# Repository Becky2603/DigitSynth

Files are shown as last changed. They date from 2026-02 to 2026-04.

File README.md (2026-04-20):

# DigitSynth

DigitSynth is a wearable MIDI controller that interacts with the Roland JD-Xi synthesiser. It allows the user to trigger chords and shape the resulting sound in real time using finger movements.

## Hardware Requirements
 
### Bill of Materials

The table below outlines the hardware components used in this project. Exact component matches are not required, and suitable alternatives will yield comparable results. However, as the software has been developed specifically for the Raspberry Pi, it is strongly recommended to retain this as the target platform.
 
| Component | Part Number | Quantity | Approx. Cost (unit)|
|---|---|---|---|
| Raspberry Pi 5 | Pi 5 4GB | 1 | £105.60 |
| Adafruit ADS1115 | 1085 | 1 | £11.18 |
| Adafruit TLC59711 | 1455 | 1 | £6.73 |
| Spectra Symbol Flex Sensor FLX| FLX-L-055-123-MP | 4 | £8.51 |
| Tactile Switch, 4.3mm | MCDTS2-1N| 4 | £0.17 |
| Kingbright L-7113IT 5mm 2V Red LED 80mcd | 56-0250 | 8 | £0.08 |
| Pisugar S Plus 5000 mAh Raspberry Pi UPS | Pisugar S Plus | 1 | £29.99 |

A MIDI-receiving device is required to complete the setup, either a hardware synthesiser or a software synthesiser running on a connected laptop. In this project, a Roland JD-Xi synthesiser was used, receiving MIDI directly from the Raspberry Pi over USB-B.

### Wiring Diagram:

Wiring diagram

## Architecture

<details>
<summary>UML class diagram</summary>

DigitSynth UML class diagram

</details>

## Software Requirements

### Toolchain
Our build system is CMake, but we provide a simple top-level Makefile to make things easy. Feel free to run the `cmake` commands manually if you are so inclined. The `install-deps.sh` script will automatically install dependencies required by DigitSynth. 

## Installing
A simple install can be performed using the `.deb` package in the latest release. Download `digitsynth-aarch64.deb`, then run ```bash sudo dpkg -i digitsynth-aarch64.deb``` in your terminal after navigating to the directory into which the archive was downloaded. The standalone binary can also be found in the release.  Note that dependencies still need to be installed. 

## Building

### 1.1 Clone the Repository
 
```bash
git clone https://github.com/RTES-Group/DigitSynth.git
cd DigitSynth
```

OR 

### 1.2 Download the release
Find the latest release on the right-hand side of this page. Download either the `.tar.gz` or `.zip`. After downloading and navigating to the download directory: 

#### `zip`
```bash 
unzip DigitSynth-xx.xx.xx.zip

cd DigitSynth-xx.xx.xx
```

#### `tar.gz`
```bash 
tar -xf DigitSynth-xx.xx.xx.tar.gz

cd DigitSynth-xx.xx.xx
```

### 2. Install Dependencies

#### Dependencies

| Library | Purpose | Source |
|---|---|---|
| IIR Filter Library | Digital IIR filter design and processing | [berndporr/iir1](https://github.com/berndporr/iir1) |
| RtMidi | Real-time MIDI input/output | [thestk/rtmidi](https://github.com/thestk/rtmidi) |
| ADS1115 API | Flex sensor measurement | [berndporr/rpi_ads1115](github.com/berndporr/rpi_ads1115) |
| libgpiod | GPIO management | [ligpiod](https://libgpiod.readthedocs.io/en/latest/building.html) | 
| libasound2-dev | ALSA development headers | [libasound2-dev](https://alsa-project.org/) |

Simply run the `install-deps.sh` script:
```bash 
./install-deps.sh
```

### 3. Enable SPI and I2C on the Raspberry Pi:
SPI must be enabled before the project will run:

```bash
sudo raspi-config
# Navigate to: Interface Options → SPI → Enable
# Navigate to: Interface Options → I2C → Enable
```

### 4. Build the project:

```bash
cd application/
make
```

### 5. Run:
```bash
build/digitsynth
```

---

## Unit tests

To run unit tests: 
```bash 
make test
```
---
## User Guide

A full user guide covering button modes, controls, and MIDI mapping is available here:

 [DigitSynth User Guide](docs/HowToUse.pdf)
 
---
## Demonstration Videos

| Demo 1 | LED Mode Demo | Demo 2 |
|---|---|---|
| Demo 1 (https://youtube.com/shorts/CaOxxR7UvKo) | Demo 2 (https://youtube.com/shorts/K6ZXAT-Ynss) | Demo 3 (https://youtube.com/shorts/oUVmrUkGGP4) |

---
## Social Media

Follow our build journey on Instagram: 

We are also awaiting a write-up on [Hackaday.com](https://hackaday.com) about our project, so keep an eye out on their blog!

---

## Contributing

See the issues tab for a list of potential contributions. In particular, we would welcome expanding support for other synths. 

---
## License

This project is licensed under the **MIT License** — see the [`LICENSE`](LICENSE) file for details.
 
You are free to use, modify, and distribute this project. We just ask that you credit the original authors.

---

## Authors & Acknowledgements

Developed by:

- **Logan Brown** — [GitHub](https://github.com/LoganBrownGU)
- **Becky Clarke** — [GitHub](https://github.com/Becky2603)
- **Dougal Harris** — [GitHub](https://github.com/DougalH1)
- **Finn McConville** — [GitHub](https://github.com/finnmcco)
- **Jamie Wedlinscky** — [GitHub](https://github.com/jwedlinscky)
  
As part of the **Real-Time Embedded Systems** module at **University of Glasgow**, *2026*.

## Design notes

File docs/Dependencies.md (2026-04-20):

# Dependencies

This document describes all dependencies required to build and run DigitSynth on Raspberry Pi.

A full installation script is available at `DigitSynth/install-deps.sh`.

---

## System Packages

Installed via `apt`:

| Package | Purpose |
|---|---|
| `autotools-dev` | Build toolchain support for autoconf-based projects |
| `autoconf-archive` | Extended macro library for autoconf |
| `libtool` | Generic shared library support |
| `pkg-config` | Compiler flag helper for installed libraries |
| `alsa` | ALSA sound system |
| `libasound2-dev` | ALSA development headers (required by RtMidi) |

---

## libgpiod

**Version:** 2.2
**Source:** https://mirrors.edge.kernel.org/pub/software/libs/libgpiod/
**Purpose:** Linux GPIO access from userspace — used for hardware pin control on the Raspberry Pi.

### Installation

```bash
curl -S https://mirrors.edge.kernel.org/pub/software/libs/libgpiod/libgpiod-2.2.tar.gz -o libgpiod.tar.gz
tar -xf libgpiod.tar.gz
cd libgpiod-2.2/
./configure --enable-bindings-cxx
make
sudo make install
```

> The `--enable-bindings-cxx` flag is required to build the C++ bindings used by this project.

---

## ADS1115 Raspberry Pi Driver

**Source:** https://github.com/berndporr/rpi_ads1115
**Purpose:** Userspace driver for the ADS1115 16-bit ADC over I2C — used to read analogue input from the flex sensors and potentiometers via SPI.

### Installation

```bash
git clone https://github.com/berndporr/rpi_ads1115.git
cd rpi_ads1115/
cmake .
make
sudo make install
```

> Requires I2C to be enabled on the Raspberry Pi. Enable via `sudo raspi-config` → Interface Options → I2C.

---

## iir1 — IIR Filter Library

**Source:** https://github.com/berndporr/iir1
**Purpose:** Digital IIR filter design and processing — used in `FlexDSP` to apply a 4th order Butterworth low-pass filter to flex sensor data.

### Installation

```bash
git clone https://github.com/berndporr/iir1.git
cd iir1
cmake .
make
sudo make install
```

### Usage in this project

Include the filter header with:

```cpp
#include <iir/Butterworth.h>
```

---

## RtMidi

**Source:** https://github.com/thestk/rtmidi
**Purpose:** Real-time MIDI input/output — used to send MIDI CC messages from the glove controller to a connected synthesiser.

### Installation

```bash
git clone https://github.com/thestk/rtmidi.git
cd rtmidi
cmake . -DRTMIDI_API_ALSA=ON -DRTMIDI_API_JACK=OFF
make
sudo make install
```

> Built with ALSA backend enabled and JACK disabled. ALSA is the default audio/MIDI layer on Raspberry Pi OS.

---

## Notes

- All libraries are installed system-wide via `sudo make install` and are picked up automatically by CMake.
- If CMake cannot find a library after installation, run `sudo ldconfig` to refresh the dynamic linker cache.
- Tested on Raspberry Pi OS 64-bit (Bookworm).

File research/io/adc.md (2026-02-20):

# ADCs
Struggling to find an ADC with a data-ready pin, all seem to be query-based. 

Checked: 
- MCP3008I (microchip)
- ADC128S022 (TI)
- MCP320418 (microchip) 
- ADS78301PWT (TI) 

Possibility of using ADS1256 (TI)
- Programmable timer
- Provides data-ready
- A little pricey (approx. £16)

Could build our own oscillator for timing
- 555 or similar
- Crystal oscillator (maybe too fast)

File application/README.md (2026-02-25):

# Raspberry Pi Application

## How to Build

Generate build files: 

```
cmake -B build
```

Build: 

```
cmake --build build/
```

### Release mode
Run the following to compile with max optimisations and no debug symbols: 

```
cmake -B build -DRELEASE=1
cmake --build build/
```

## How to Run

```
./build/digitsynth
```

## Running unit test

(After building)
```
cmake --build build/ -- test
```

## Dependencies

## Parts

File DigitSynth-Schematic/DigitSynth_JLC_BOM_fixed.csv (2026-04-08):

Designator | Comment | Footprint | LCSC Part # | Mouser Part #
C1 | 100nF | C_0603_1608Metric | C14663
C3 | 100n | C_0603_1608Metric | C14663
C4 | 100n | C_0603_1608Metric | C14663
C5 | 100n | C_0603_1608Metric | C14663
C6 | 100n | C_0603_1608Metric | C14663
C_AVDD_1 | 0.1u | C_0603_1608Metric | C14663
C_AVDD_2 | 10u | C_0805_2012Metric | C15850
C_DVDD_1 | 100n | C_0603_1608Metric | C14663
C_FILT1 | 0.33u | C_0603_1608Metric | C1615
C_FILT2 | 0.33u | C_0603_1608Metric | C1615
C_FILT3 | 0.33u | C_0603_1608Metric | C1615
C_FILT4 | 0.33u | C_0603_1608Metric | C1615
D1 | BZX84C5V6 | SOT-23 | C82471
FB1 | 330Ω | L_0603_1608Metric | C79913
R1 | 1k | R_0603_1608Metric | C21190
R2 | 1k | R_0603_1608Metric | C21190
R3 | 1k | R_0603_1608Metric | C21190
R4 | 1k | R_0603_1608Metric | C21190
R5 | 10k | R_0603_1608Metric | C25804
R6 | 10k | R_0603_1608Metric | C25804
R7 | 10k | R_0603_1608Metric | C25804
R8 | 12k | R_0603_1608Metric | C22790
R9 | 12k | R_0603_1608Metric | C22790
R10 | 12k | R_0603_1608Metric | C22790
R11 | 12k | R_0603_1608Metric | C22790
R12 | 10k | R_0603_1608Metric | C25804
R13 | 10k | R_0603_1608Metric | C25804
R14 | 10k | R_0603_1608Metric | C25804
R15 | 10k | R_0603_1608Metric | C25804
R16 | 5K1 | R_0603_1608Metric | C23186
R17 | 5K1 | R_0603_1608Metric | C23186
U1 | ADS1256IDBR | SSOP-28_5.3x10.2mm_P0.65mm | C28186

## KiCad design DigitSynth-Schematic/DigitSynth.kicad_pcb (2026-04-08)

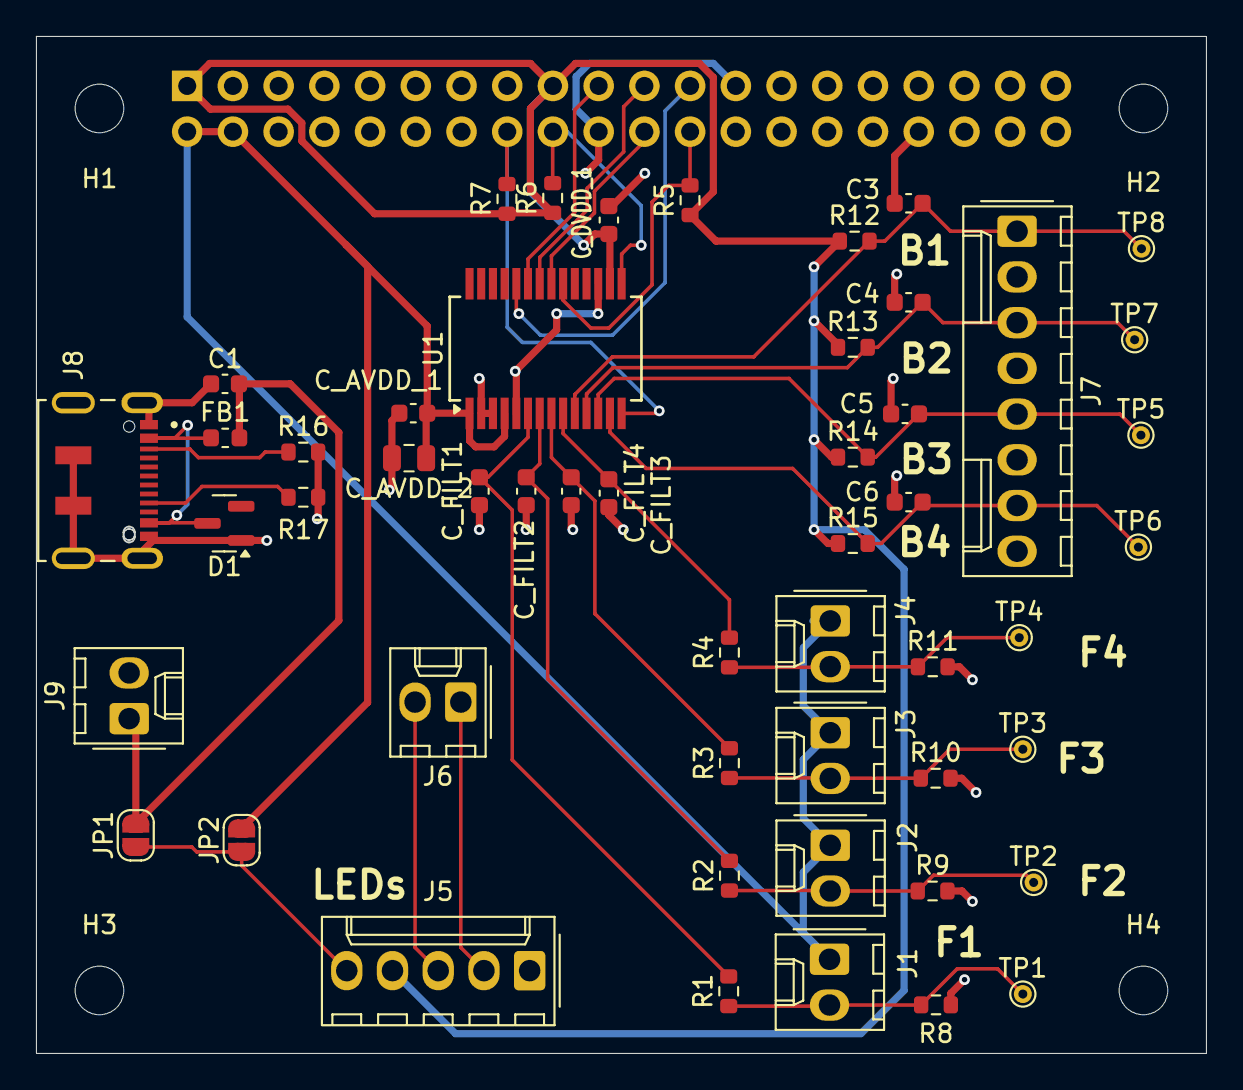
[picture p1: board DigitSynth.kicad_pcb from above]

Board: 2 copper layers, 65.0 x 56.5 mm, 56 parts (1 on the bottom side), 29 nets.

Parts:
C1: 100nF; C_0603_1608Metric
C3, C4, C5, C6: 100n; C_0603_1608Metric
C_AVDD_1: 0.1u; C_0603_1608Metric
C_AVDD_2: 10u; C_0805_2012Metric
C_DVDD_1: 100n; C_0603_1608Metric
C_FILT1, C_FILT2, C_FILT3, C_FILT4: 0.33u; C_0603_1608Metric
D1: BZX84C5V6; SOT-23
FB1: 330Ω; L_0603_1608Metric
H1, H2, H3, H4: MountingHole; MountingHole_2.7mm_M2.5
J1, J2, J3, J4, J6, J9: Conn_01x02_Pin; Molex_KK-254_AE-6410-02A_1x02_P2.54mm_Vertical
J5: Conn_01x05_Pin; Molex_KK-254_AE-6410-05A_1x05_P2.54mm_Vertical
J7: Conn_01x08; Molex_KK-254_AE-6410-08A_1x08_P2.54mm_Vertical
J8: USB_C_Receptacle_USB2.0_JAE; JAE_DX07S016JA1R1500
JP1, JP2: Jumper_2_Open; SolderJumper-2_P1.3mm_Open_RoundedPad1.0x1.5mm
J_RPI1: THD-20-R; PinHeader_2x20_P2.54mm_Vertical
R1, R2, R3, R4: 1k; R_0603_1608Metric
R5, R6, R7, R12, R13, R14, R15: 10k; R_0603_1608Metric
R8, R9, R10, R11: 12k; R_0603_1608Metric
R16, R17: 5K1; R_0603_1608Metric
TP1, TP2, TP3, TP4, TP5, TP6, TP7, TP8: TestPoint; TestPoint_THTPad_D1.0mm_Drill0.5mm
U1: ADS1256IDBR; SSOP-28_5.3x10.2mm_P0.65mm

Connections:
+3V3_PI: C_DVDD_1.1, J5.4, J_RPI1.1, J_RPI1.17, R5.1, R6.1, R7.1, R12.1, R13.1, R14.1, R15.1, U1.16 (DVDD)
+5V_EXT: C1.1, FB1.2, J9.1, JP1.2 (B)
+5V_PI: C_AVDD_1.1, C_AVDD_2.1, J1.1, J2.1, J3.1, J4.1, JP2.2 (B), J_RPI1.2, J_RPI1.4, U1.1 (AVDD), U1.4 (VREFP)
/ADC Flex/ADC_CS: J_RPI1.24, R5.2, U1.20 (~CS)
/ADC Flex/ADC_DRDY: J_RPI1.22, U1.21 (~DRDY)
/ADC Flex/ADC_RESET: J_RPI1.18, R6.2, U1.15 (~RESET)
/ADC Flex/ADC_SYNC_PDWN: J_RPI1.16, R7.2, U1.14 (~SYNC,_~PDWN)
/ADC Flex/BTN_1: C3.1, J7.1, R12.2, TP8.1, U1.10 (AIN4)
/ADC Flex/BTN_2: C4.1, J7.3, R13.2, TP7.1, U1.11 (AIN5)
/ADC Flex/BTN_3: C5.1, J7.5, R14.2, TP5.1, U1.12 (AIN6)
/ADC Flex/BTN_4: C6.1, J7.7, R15.2, TP6.1, U1.13 (AIN7)
/ADC Flex/FLEX1_V: J1.2, R1.1, R8.1, TP1.1
/ADC Flex/FLEX2_V: J2.2, R2.1, R9.1, TP2.1
/ADC Flex/FLEX3_V: J3.2, R3.1, R10.1, TP3.1
/ADC Flex/FLEX4_V: J4.2, R4.1, R11.1, TP4.1
/ADC Flex/SPI0_MISO: J_RPI1.21, U1.22 (DOUT)
/ADC Flex/SPI0_MOSI: J_RPI1.19, U1.23 (DIN)
/ADC Flex/SPI0_SCLK: J_RPI1.23, U1.24 (SCLK)
GND: C1.2, C3.2, C4.2, C5.2, C6.2, C_AVDD_1.2, C_AVDD_2.2, C_DVDD_1.2, C_FILT1.2, C_FILT2.2, C_FILT3.2, C_FILT4.2, D1.1 (A), J5.1, J7.2, J7.4, J7.6, J7.8, J8.A1 (GND), J8.A12 (GND), J8.S1 (SHIELD), J9.2, J_RPI1.6, J_RPI1.9, J_RPI1.14, J_RPI1.20, J_RPI1.25, J_RPI1.30, J_RPI1.34, J_RPI1.39, R8.2, R9.2, R10.2, R11.2, R16.2, R17.2, U1.2 (AGND), U1.3 (VREFN), U1.5 (AINCOM), U1.17 (DGND)
unnamed: D1.3 (K), FB1.1, J8.A4 (VBUS), J8.B4 (VBUS)
unnamed: J5.5, JP1.1 (A), JP2.1 (A)
unnamed: J8.A5 (CC1), R16.1
unnamed: J8.B5 (CC2), R17.1
unnamed: C_FILT1.1, R1.2, U1.6 (AIN0)
unnamed: C_FILT2.1, R2.2, U1.7 (AIN1)
unnamed: C_FILT3.1, R3.2, U1.8 (AIN2)
unnamed: C_FILT4.1, R4.2, U1.9 (AIN3)
SPI2_CLK: J5.2, J6.1
SPI2_DATA: J5.3, J6.2

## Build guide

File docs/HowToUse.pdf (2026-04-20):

# How to Use DigitSynth

Physical Setup
- Left index finger
- LED: TLC59711 pins G0
- Button: Pi GPIO 14
- Left middle finger
- LED: TLC59711 pins G1
- Button: Pi GPIO 15
- Left ring finger
- LED: TLC59711 pins R0
- Button: Pi GPIO 18
- Left pinkie
- LED: TLC59711 pins B1
- Button: Pi GPIO 23
- Right index finger
- LED: TLC59711 pins B0
- Flex sensor: ADC pin A3
- Right middle finger
- LED: TLC59711 pins R2
- Flex sensor: ADC pin A0
- Right ring finger
- LED: TLC59711 pins R1
- Flex sensor: ADC pin A2
- Right pinkie
- LED: TLC59711 pins G2
- Flex sensor: ADC pin A1

How it works
DigitSynth is a wearable MIDI controller that interacts with the Roland JD-Xi synthesiser. It allows the user to trigger chords and shape the resulting sound in real time using finger movements.

Chords are sustained infinitely once triggered, and only stop when switching to a new chord.

The right hand is used to shape the sound. Each flex sensor controls a different synth parameter. The index finger adjusts the cutoff frequency of a low-pass filter, allowing the sound to move from bright and sharp to dull and muted as the finger bends.

The middle and ring fingers control a low-frequency oscillator (LFO) which modulates the filter. The middle finger sets the LFO rate, which determines how quickly the modulation occurs, while the ring finger controls the depth of the LFO i.e. how strong the effect is.

The character of the modulation depends on the shape of the LFO. A sine wave produces smooth changes, a square wave creates sudden switching between values, and the sample-and-hold (SH) mode introduces a random stepped modulation.

The pinkie controls pitch detuning. When held straight, the pitch remains stable. As the finger bends, the pitch becomes increasingly detuned.

Modes of Operation
DigitSynth operates in two modes: a chord mode for live changes between chords, and a normal mode for extended system control.

In chord mode, the four buttons on the left hand each correspond to a specific chord. Pressing a button will immediately switch to that chord. The index finger triggers an Fmaj9 chord, the middle finger plays an Amin11 chord, the ring finger plays a Gsus2 chord, and the pinkie plays a Cmaj7 chord. Pressing the button corresponding to the currently active chord exits chord mode and returns the system to normal mode.

In normal mode, the same buttons are used to control system behaviour. The index finger is used to enter chord mode. The middle finger toggles the LFO on or off. The ring finger cycles through the available LFO shapes (sine, square, and SH). The pinkie switches between the two LED display modes.

LED Behaviour
The LEDs either provide visual feedback or an aesthetic animation, depending on user selection.

In responsive mode, the LEDs communicate the internal state of the system. The left index LED indicates whether the system is in normal mode (on) or chord mode (off). The left middle finger LED shows whether the LFO is enabled (on). The left ring finger LED indicates the current LFO shape using brightness levels: off for sine, medium for square, and full brightness for SH. The left pinkie LED is always on in responsive mode. The brightness of the LEDs on the right hand reflect the position of the flex sensors, giving a visual indication of parameter values.

Alternatively, the LEDs can be set to a ripple mode, where a continuous animated pattern plays across all LEDs. In this mode, no parameter feedback is shown.

Startup Behaviour
On boot, DigitSynth starts in normal mode with an Amin11 chord playing (the chord mapped to the left middle finger). The LEDs are in responsive mode, and the LFO is enabled with a sine wave shape.

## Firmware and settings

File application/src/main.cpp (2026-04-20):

#include "synth-controller.hpp"
#include "tlc59711.hpp"
#include "adc-driver.hpp"
#include "button-driver.hpp"
#include "flex-sensor.hpp"
#include "gpio.hpp"
#include "midi-driver.hpp"
#include "patterns.hpp"
#include "voltage-scaler.hpp"
#include <condition_variable>
#include <iostream>
#include <memory>
#include <mutex>

int main() {
    gpio::setupGpio();
    std::condition_variable c;
    std::mutex m;
    bool done = false;
    
    auto bd = std::make_unique<button_driver::ButtonDriver>();
    bd->registerAllButtonsCallback([&c, &m, &done] () {
        std::unique_lock lock(m);
        done = true;
        lock.unlock();
        c.notify_all();
    });
    
    auto tlc = led_driver::TLC59711("/dev/spidev0.0", 1'000'000);
    auto pattern = led_pattern::PatternRipple(tlc);
    tlc.start();
    SynthController synth(
        tlc,
        pattern,
        std::move(bd),
        std::make_unique<flex_sensor::FlexSensor>(
            std::make_unique<adc_driver::Ads1115Driver>(),
            std::make_unique<voltage_scaler::VoltageScaler>()
        ),
        std::make_unique<midi_driver::MidiDriver>()
    );
   

    getchar();
    
    std::cout <<"stop\n";
    
    return 0;
}

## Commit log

2026-02-04 ADC research
2026-02-20 Basic UML diagram of ADC software architecture
2026-03-02 ADC driver classes
2026-03-03 Started ADC driver
    Added Makefile to make running easier
    Added tests for ADC driver
2026-03-03 Create midi-thread-scope
    MIDI encoding thread documentation.
    Defines scope and responsibility of this section of the project, with inputs (button + flex sensor data), processing steps and outputs (USB MIDI messages).
2026-03-03 Rename midi-thread-scope to midi-thread-scope.md
    Updating to .md
2026-03-06 Delete midi-thread-scope.md
    document no longer relevant and replaced by a clearer specification
2026-03-08 Add initial LEDDriver header with class skeleton
2026-03-08 Modifying LEDDriver.h for 10-LED brightness input
2026-03-08 Simplifying the header file for single chip application. writeSPI set to private to avoid duplication and removed numchips as we are no longer daisy chaining
2026-03-08 creation of cpp skeleton for LED pwm driver. includes constants declartaion and function defintions
2026-03-17 Replace SPI-based TLC59711 driver with arbitrary GPIO approach
    New implementation bit-bangs DATA and CLOCK onto GPIO17 and GPIO27.
    The threading model is also reworked: the new driver blocks on a pipe read() and
    wakes only when the caller writes a new LEDFrame, following the
    blocking I/O pattern for kernel-level thread wakeup.
    Type Brightness added for normalised brightness values passed ot function.
2026-03-17 hello world for GPIO init and LED toggling.
    Stub for LED driver implementation
2026-03-18 Fixed bit order bugs and the like
    [main.cpp]
2026-03-24 Removed wiringPi
2026-03-24 Main application. Needs testing with powersupply when back in the lab
2026-03-25 ripple pattern with 3 simultaneous fingers
2026-04-02 commiting to merge with gpio-driver
2026-04-02 Basic flex sensor working
    [main.cpp]
2026-04-08 Updated patterns to be threadsafe and allign with guidance
2026-04-08 test for TLC added static unit tests for toGS and FRAME_TO_GS
2026-04-08 test for TLC adding concurrency test for update() thread safety
2026-04-08 Basic integration of LEDs and flex
    [main.cpp]
2026-04-08 Add midi-driver.cpp
2026-04-13 Documented button driver
2026-04-13 Doc'd flex sensor
2026-04-13 Fixed button callback types
    Renamed `ButtonCallback -> SingleButtonCallback`
    Created type for all buttons callback (`AllButtonsCallback`)
2026-04-13 Added new button callback types to `button-driver.cpp` (#54)
2026-04-13 unit test for updated flex sensor handling
2026-04-14 fix LED logic issues
2026-04-14 fix pattern issue caused by double button press
2026-04-20 Update README.md
    Added flex sensor resistor justification
2026-04-20 Setup threading and waiting for flexsensor
    Exits cleanly
2026-04-20 flex sensor test passes
2026-04-20 Document resistor selection and voltage divider for flex sensors
    Added detailed explanation of resistor selection and voltage divider calculations for flex sensors, including operating ranges and ADC considerations.
